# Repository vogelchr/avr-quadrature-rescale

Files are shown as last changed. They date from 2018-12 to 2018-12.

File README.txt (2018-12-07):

I had an older piece of hardware which used a quadrature encoder,
unfortunately I wasn't able to purchase the exact replacement, because
I needed a low number of detents *and* only one pulse-step per detent.

The old encoder had detents and quadrature outputs which look like this:

** Old Encoder **

    detents
     v    v    v    v    v    v    v    v    v    v    v    v    v
   +----:----+         +----:----+         +----:----+         +---:-
   |         |         |         |         |         |         |
---+         +----:----+         +----:----+         +----:----+

        +----:----+         +----:----+         +----:----+         +-
        |         |         |         |         |         |         |
---:----+         +----:----+         +----:----+         +----:----+

The new decoders I found did two steps, or even one cycle per detent.

** New Encoder **

  detents
  V       V       V       V       V       V       V
 +-:-+   +-:-+   +-:-+   +-:-+   +-:-+   +-:-+   +-:-+   
 |   |   |   |   |   |   |   |   |   |   |   |   |   |   
-+   +-:-+   +-:-+   +-:-+   +-:-+   +-:-+   +-:-+   +-:-

   +-:-+   +-:-+   +-:-+   +-:-+   +-:-+   +-:-+   +-:-+   
   |   |   |   |   |   |   |   |   |   |   |   |   |   |   
-:-+   +-:-+   +-:-+   +-:-+   +-:-+   +-:-+   +-:-+   +-:-

The enclosing PCB houses a ATTiny26 (one of the most useless chips of the)
attiny series, I think, but I had a few spare. It converts puslses of a
"new encoder", divides then by a ratio of 4 steps/step, and outputs pulses
compatible to the old scheme. That's all it does.

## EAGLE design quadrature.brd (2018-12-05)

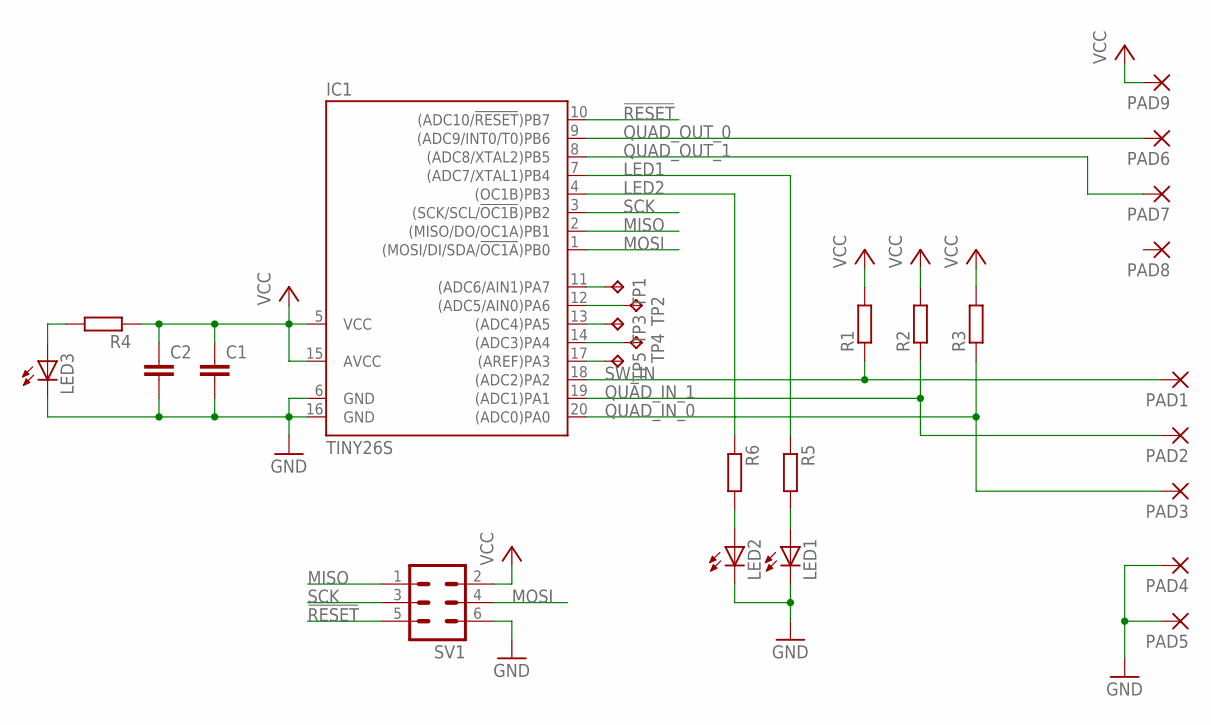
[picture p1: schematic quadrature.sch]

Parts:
C1, C2: C-EUC0603; C0603
IC1: TINY26S; SO20L
LED1, LED2, LED3: LEDCHIP-LED0603; CHIP-LED0603
PAD1, PAD2, PAD3, PAD4, PAD5, PAD6, PAD7, PAD8, PAD9: 1,6/0,8
R1, R2, R3, R4, R5, R6: R-EU_R0603; R0603
SV1: ML6
TP1, TP2, TP3, TP4, TP5: TPB1,27; B1,27

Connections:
!RESET: IC1.10 ((ADC10/!RESET!)PB7), SV1.5
GND: C1.2, C2.2, IC1.6 (GND), IC1.16 (GND), LED1.C, LED2.C, LED3.C, PAD4.1, PAD5.1, SV1.6
LED1: IC1.7 ((ADC7/XTAL1)PB4), R5.1
LED2: IC1.4 ((OC1B)PB3), R6.1
MISO: IC1.2 ((MISO/DO/OC1A)PB1), SV1.1
MOSI: IC1.1 ((MOSI/DI/SDA/!OC1A!)PB0), SV1.4
unnamed: IC1.11 ((ADC6/AIN1)PA7), TP1.TP
unnamed: LED3.A, R4.2
unnamed: IC1.12 ((ADC5/AIN0)PA6), TP2.TP
unnamed: IC1.13 ((ADC4)PA5), TP3.TP
unnamed: LED1.A, R5.2
unnamed: LED2.A, R6.2
unnamed: IC1.14 ((ADC3)PA4), TP4.TP
unnamed: IC1.17 ((AREF)PA3), TP5.TP
QUAD_IN_0: IC1.20 ((ADC0)PA0), PAD3.1, R3.1
QUAD_IN_1: IC1.19 ((ADC1)PA1), PAD2.1, R2.1
QUAD_OUT_0: IC1.9 ((ADC9/INT0/T0)PB6), PAD6.1
QUAD_OUT_1: IC1.8 ((ADC8/XTAL2)PB5), PAD7.1
SCK: IC1.3 ((SCK/SCL/!OC1B!)PB2), SV1.3
SW_IN: IC1.18 ((ADC2)PA2), PAD1.1, R1.1
VCC: C1.1, C2.1, IC1.5 (VCC), IC1.15 (AVCC), PAD9.1, R1.2, R2.2, R3.2, R4.1, SV1.2

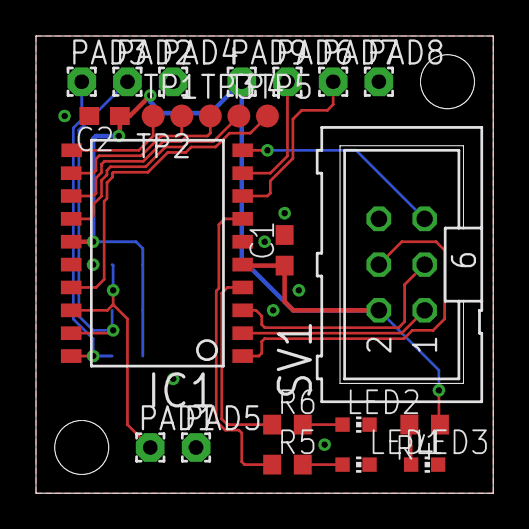
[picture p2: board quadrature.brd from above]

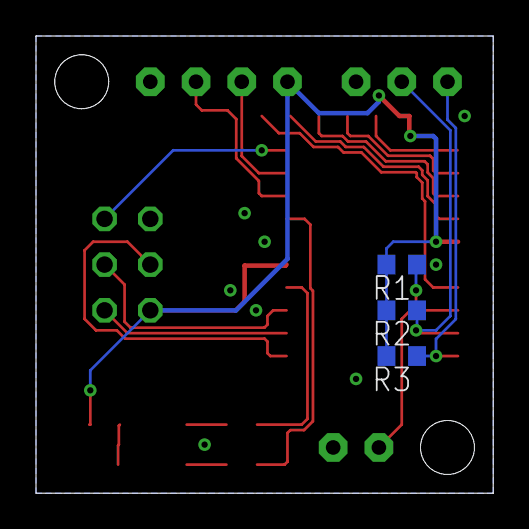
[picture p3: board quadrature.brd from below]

Board: 2 copper layers, 25.4 x 25.4 mm, 27 parts (3 on the bottom side), 21 nets.

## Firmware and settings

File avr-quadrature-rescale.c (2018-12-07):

#include <avr/io.h>
#include <avr/interrupt.h>
#include <avr/pgmspace.h>

/*
 *
 *               +---------------+
 *  MOSI(ISP)    |  1 PB0 PA0 20 |      QIN0
 *  MISO(ISP)    |  2 PB1 PA1 19 |      QIN1
 *  SCK(ISP)     |  3 PB2 PA2 18 |      Switch
 *  LED2 OC1B    |  4 PB3 PA3 17 |      TP
 *               |  5 Vcc GND 16 |
 *               |  6 GND Vcc 15 |
 *  LED1         |  7 PB4 PA4 14 |      TP
 *  QOUT1        |  8 PB5 PA5 13 |      TP
 *  QOUT0        |  9 PB6 PA6 12 |      TP
 *  \Reset       | 10 PB7 PA7 11 |      TP
 *               +---------------+
 */

/*
 *  Gray encoding of counter cnt:
 *    gray = (bin & 0x03) ^ (0x01 & (bin >> 1))
 *  
 *  Cnt  bin  gray
 *  ---:-----:----
 *   0 : 0 0 : 0 0
 *   1 : 0 1 : 0 1
 *   2 : 1 0 : 1 1
 *   3 : 1 1 : 1 0
 */


const signed char quad_state_tbl[16] PROGMEM = {
	/* index is (old_bin << 2) | new_quadrature */
	[0b0001]=+1, /* from [..] 0 -> [.H] 1 */
	[0b0111]=+1, /* from [.H] 1 -> [HH] 2 */
	[0b1010]=+1, /* from [HH] 2 -> [H.] 3 */
	[0b1100]=+1, /* from [H.] 3 -> [..] 0 */

	[0b0010]=-1, /* from [..] 0 -> [H.] 3 */
	[0b1111]=-1, /* from [H.] 3 -> [HH] 2 */
	[0b1001]=-1, /* from [HH] 2 -> [.H] 1 */
	[0b0100]=-1, /* from [.H] 1 -> [..] 0 */
};

#define DDR_QOUT DDRB
#define PORT_QOUT PORTB
#define BV_QOUT0 _BV(6)
#define BV_QOUT1 _BV(5)

#define PORT_QIN PORTA
#define DDR_QIN  DDRA
#define PIN_QIN  PINA
#define BV_QIN0  _BV(0)
#define BV_QIN1  _BV(1)

#define DDR_LED1  DDRB
#define PORT_LED1 PORTB
#define BV_LED1   _BV(4)

#define DDR_LED2  DDRB
#define PORT_LED2 PORTB
#define BV_LED2   _BV(3)

static void
set_led1(int val) {
	if (val)
		PORT_LED1 |= BV_LED1;
	else
		PORT_LED1 &= ~BV_LED1;
}

static void
set_led2(int val) {
	if (val)
		PORT_LED2 |= BV_LED2;
	else
		PORT_LED2 &= ~BV_LED2;
}

static unsigned char
read_quad_input() {
	unsigned char q = 0;
	/* low active inputs */
	if (!(PIN_QIN & BV_QIN0))
		q |= 0x01;
	if (!(PIN_QIN & BV_QIN1))
		q |= 0x02;
	return q;
}

static void
write_quad_output(unsigned char q) {
	/* low active outputs, pulldown via DDR=1, PORT=0 */
	if (q & 0x01) {
		PORT_QOUT &= ~BV_QOUT0;
		DDR_QOUT  |= BV_QOUT0;
	} else {
		DDR_QOUT &= ~BV_QOUT0;
		PORT_QOUT |= BV_QOUT0;
	}

	if (q & 0x02) {
		PORT_QOUT &= ~BV_QOUT1;
		DDR_QOUT |= BV_QOUT1;
	} else {
		DDR_QOUT &= ~BV_QOUT1;
		PORT_QOUT |= BV_QOUT1;
	}
}

static unsigned char led2_dir;
static uint16_t led2_ctr;

/* timer overflow to amuse the user with a fading led */
ISR(TIMER1_OVF1_vect) {
	unsigned char dir = led2_dir;
	uint16_t ctr = led2_ctr;

#if 0
	if (ctr == 1023)
		dir = 0; /* count down */
	if (ctr == 0)
		dir = 1; /* count up */

	if (dir)
		ctr++;
	else
		ctr--;

	OCR1B = ((ctr >> 2)*(ctr >> 2)) >> 8;
#endif

	led2_ctr = ctr;
	led2_dir = dir;
}

static unsigned char
bin_to_gray(unsigned char ctr)
{
	return (ctr & 0x03) ^ (0x01 & (ctr >> 1));
}

/* static unsigned char quad_last; */
static uint16_t quad_ctr=1; /* don't start at the ffff -> 0000 wraparound! */

static void
process_quadrature() {
	signed char s;
	unsigned char q=0;

	set_led1(quad_ctr & 0x01);
	set_led2(quad_ctr & 0x02);

	q = read_quad_input();
	s = pgm_read_byte(&quad_state_tbl[((quad_ctr & 0x03) << 2) | q]);
	quad_ctr += s;

	/*
	 * The detents are around the 0 mark of the input encoding, hence
	 * we don't want to change the quadrature output when changing
	 * from 0..3, because that would be right on the edge of the detent.
	 * If we output (ctr+1)>>2, that's more towards the middle between
	 * detents.
	 *
	 *  detent
	 *   |                       |                       |
	 *   V                       V                       V
	 *  
	 *   0 --- 1 --- 2 --- 3 --- 4 --- 5 --- 6 --- 7 --- 8 ctr from quad input
	 *   0 --- 0 --- 0 --- 0 --- 1 --- 1 --- 1 --- 1 --- 2 
	 *                        ^                       ^   <--- ctr >> 2
	 *
	 *   1 --- 2 --- 3 --- 4 --- 5 --- 6 --- 7 --- 8 --- 9 ctr + 1
	 *   0 --- 0 --- 0 --- 1 --- 1 --- 1 --- 1 --- 2 --- 2
	 *                  ^                       ^         <--- ctr+1 >> 2
	 *
	 */
	q = bin_to_gray((quad_ctr+1) >> 2);
	write_quad_output(q);

}

int
main() {
	/* setup LEDs */
	DDR_LED1 |= BV_LED1;
	DDR_LED2 |= BV_LED2;
	PORT_LED1 |= BV_LED1;
	PORT_LED2 |= BV_LED2;

	/* inputs, pullup */
	DDR_QIN  &= ~ BV_QIN0; /* QIN0 is input */
	DDR_QIN  &= ~ BV_QIN1; /* QIN0 is input */
	PORT_QIN |= BV_QIN0; /* enable pullup for QIN 0 */
	PORT_QIN |= BV_QIN1; /* enable pullup for QIN 1 */

	/* outputs, enable DDR to pull low */
	DDR_QOUT  &= ~BV_QOUT0;
	DDR_QOUT  &= ~BV_QOUT1;
	PORT_QOUT &= ~BV_QOUT0;
	PORT_QOUT &= ~BV_QOUT1;

#if 0
	/* datasheet pg 73, fast PWM mode, set output on bottom, clr on match */
	TCCR1A = _BV(COM1B1) | _BV(PWM1B);
	TCCR1B = _BV(CS12); /* clkio /256 */
	TIMSK |= _BV(TOIE1) ; /* timer overflow */
	OCR1B = 0x10;
	OCR1C = 0xff;
#endif

	sei(); /* enable interrupts */

	quad_ctr = bin_to_gray(read_quad_input());
	while (1)
		process_quadrature();
}

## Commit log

2018-12-05 eagle pcb files
    [quadrature.brd, quadrature.sch]
2018-12-07 Fixed relation from input to gray code, adjust to detent position.
    Adjusted the decoding table, so that it is indexed by counter values
    instead of "old_quadrature_input". We can get rid of one varibale
    that way, also we have a fixed relation from input states to the
    2 MSBs of the counter.
    As the counters are now directly related to the quadrature inputs,
    we can further adjust the point at which the output signals change
    to one particular state change in quadrature input signals. Hence
    we can make the counter display change more closely to the
    physical detent, this improves the "feel" when changing parameters.
    [avr-quadrature-rescale.c]
